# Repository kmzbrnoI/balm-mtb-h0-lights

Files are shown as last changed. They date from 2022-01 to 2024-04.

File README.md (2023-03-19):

Osvětlení vozů malý Balm H0
===========================

Tento repozitář obsahuje podklady pro výrobu dekodéru osvětlení vlečných vozů
Balm firmy MTBmodel.

Osvětlení se skládá z horní desky ([pcb](pcb), montuje se pod strop vozů) a dvou
čelních desek ([pcb-head](pcb-head)) pro koncová světla. Na horní desce je procesor
PIC12F629, do kterého se nahrává firmware ze složky [fw](fw),

## Návod k použití

Návod obsahuje popis základních parametrů osvětlení.

* [Webový návod](https://docs.google.com/document/d/e/2PACX-1vRgrOjyaV_YPN3vRX59pJFN3mEdiZDsYugB_XFN0bcXFv8iJtmIPFT6zj8s5dFSr0we1PM2x35lkkI6/pub)
* [PDF](https://drive.google.com/file/d/1UF51u17YCr2_-8sSnn3kVr8-1jqHwtga/view)

## Autoři

* Autorem DPS je [Jan Horáček](mailto:jan.horacek@kmz-brno.cz).
* Autory firmwaru jsou: Paco Canada, Michal Petrilak,
  [Jan Horáček](mailto:jan.horacek@kmz-brno.cz).

## Licence

Hardware je vydán pod licencí [Creative Commons Attribution-ShareAlike 4.0
License](https://creativecommons.org/licenses/by-sa/4.0/) jako openhardware
projekt. Kdokoliv si může stáhnout data, přispět k projektu, vyrobit si vlastní
DPS nebo dokonce vyrobené DPS využít pro komerční účely.

Firmware je převzat od [Paco](https://usuaris.tinet.cat/fmco/home_en.htm)
[Function decoder with 4 outputs v.2](https://usuaris.tinet.cat/fmco/home_en.htm).

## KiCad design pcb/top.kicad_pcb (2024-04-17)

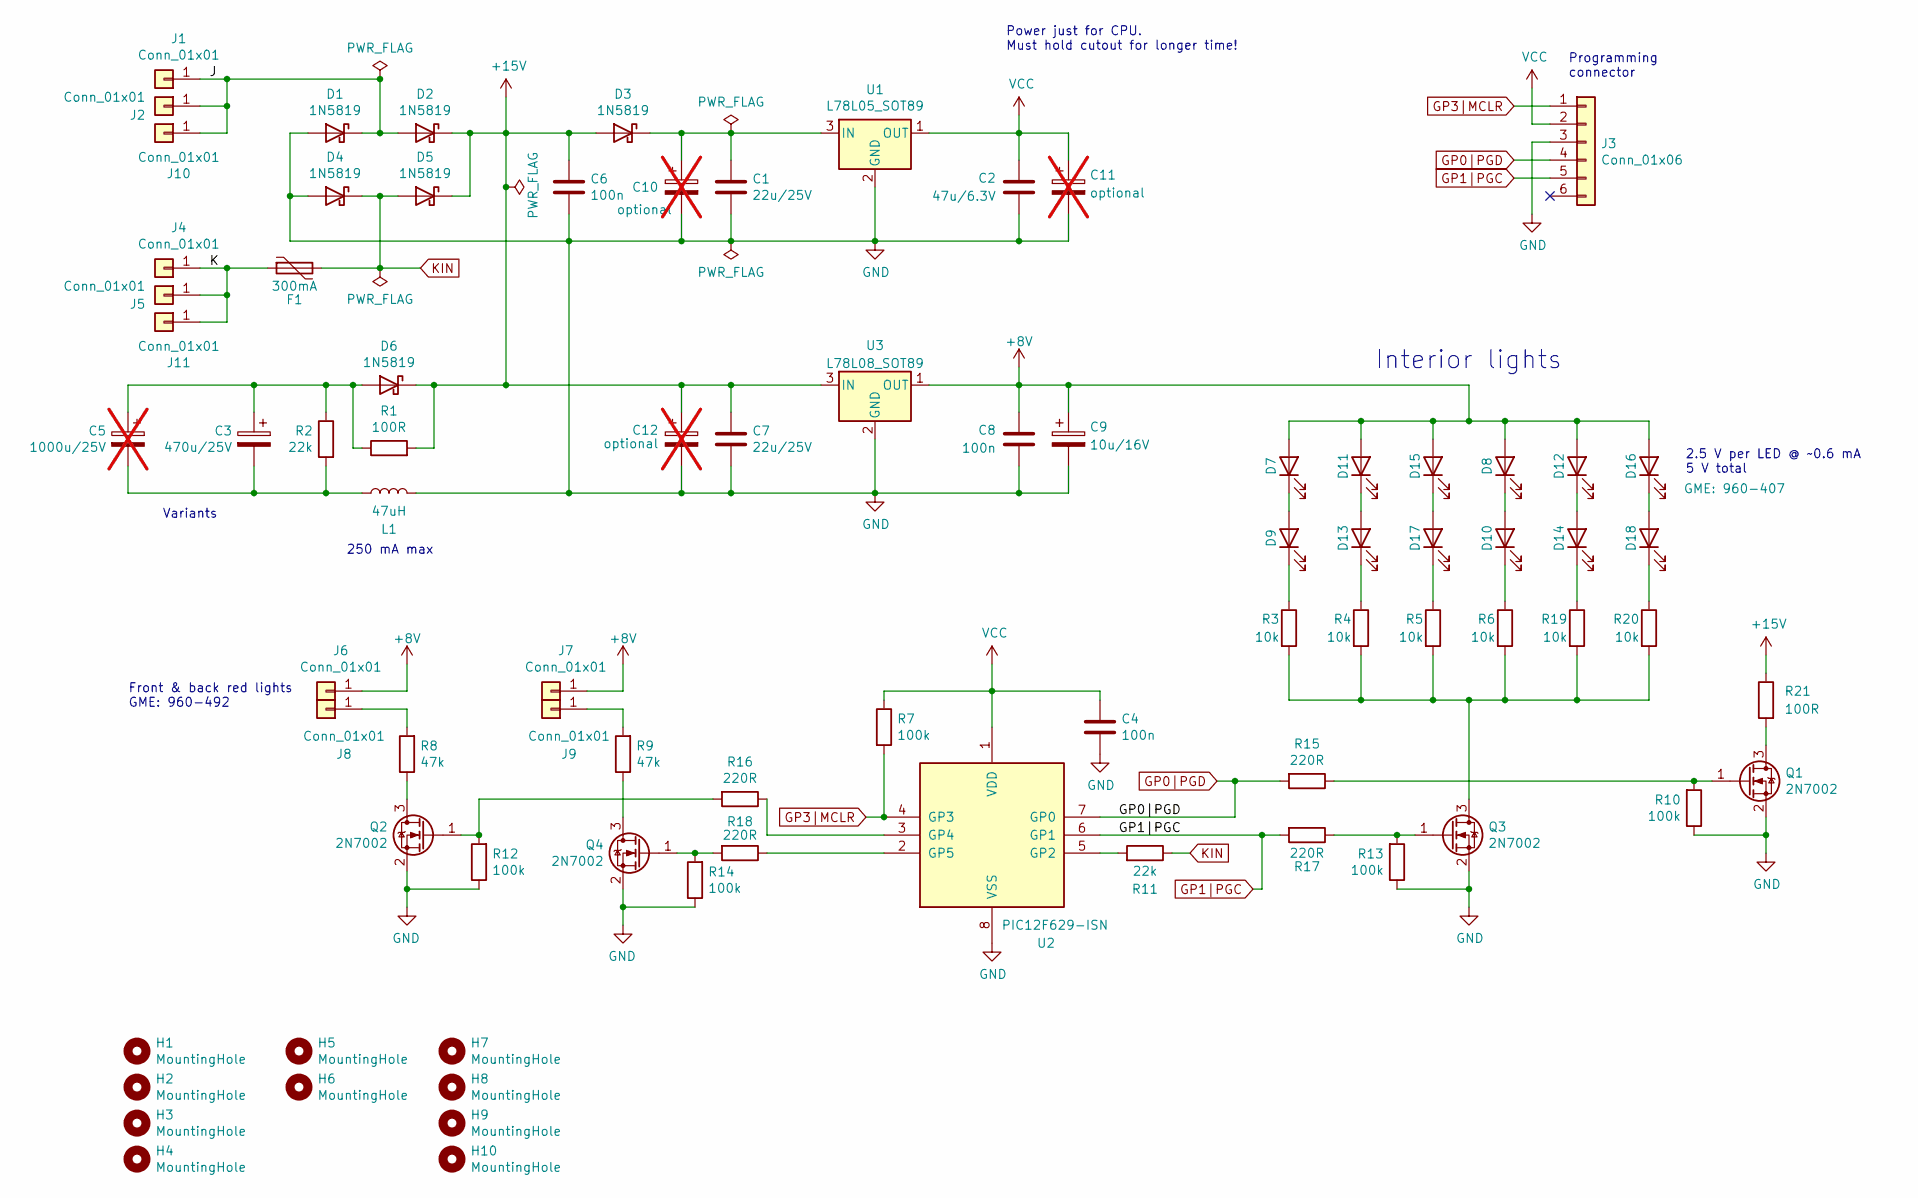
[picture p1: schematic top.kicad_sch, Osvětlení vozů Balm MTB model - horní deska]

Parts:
C1, C7: 22u/25V; C_0805_2012Metric_Pad1.18x1.45mm_HandSolder; LCSC C45783
C2: 47u/6.3V; C_0805_2012Metric_Pad1.18x1.45mm_HandSolder; LCSC C16780
C3: 470u/25V; CP_Radial_D8.0mm_P3.50mm; JLCPCB_IGNORE true
C4, C6, C8: 100n; C_0805_2012Metric_Pad1.18x1.45mm_HandSolder; LCSC C49678
C5: 1000u/25V; CP_Radial_D10.0mm_P5.00mm; JLCPCB_IGNORE true; not fitted
C9: 10u/16V; CP_EIA-3216-10_Kemet-I; LCSC C7171
C10, C11, C12: optional; CP_EIA-3216-10_Kemet-I; JLCPCB_IGNORE true; not fitted
D1, D2, D3, D4, D5, D6: 1N5819; D_SOD-123; LCSC C8598
D7, D8, D9, D10, D11, D12, D13, D14, D15, D16, D17, D18: LED; LED_PLCC_2835_Handsoldering; JLCPCB_IGNORE true
F1: 300mA; Fuse_1206_3216Metric_Pad1.42x1.75mm_HandSolder; LCSC C151132
H1, H2, H3, H4, H5, H6: MountingHole; MountingHole_2.7mm_M2.5; JLCPCB_IGNORE true
H7, H8, H9, H10: MountingHole; MountingHole_2.2mm_M2; JLCPCB_IGNORE true
J1, J2, J4, J5, J10, J11: Conn_01x01; PinHeader_1x01_P2.54mm_Vertical; JLCPCB_IGNORE true
J3: Conn_01x06; PinHeader_1x06_P2.54mm_Vertical; JLCPCB_IGNORE true
J6, J7, J8, J9: Conn_01x01; TestPoint_THTPad_D1.5mm_Drill0.7mm; JLCPCB_IGNORE true
L1: 47uH; L_Axial_L6.6mm_D2.7mm_P10.16mm_Horizontal_Vishay_IM-2; JLCPCB_IGNORE true
Q1, Q2, Q3, Q4: 2N7002; SOT-23_Handsoldering; LCSC C8545
R1, R21: 100R; R_2512_6332Metric_Pad1.40x3.35mm_HandSolder; LCSC C364154
R2, R11: 22k; R_0805_2012Metric_Pad1.20x1.40mm_HandSolder; LCSC C17560
R3, R4, R5, R6, R19, R20: 10k; R_0805_2012Metric_Pad1.20x1.40mm_HandSolder; LCSC C17414
R7, R10, R12, R13, R14: 100k; R_0805_2012Metric_Pad1.20x1.40mm_HandSolder; LCSC C149504
R8, R9: 47k; R_0805_2012Metric_Pad1.20x1.40mm_HandSolder; LCSC C17713
R15, R16, R17, R18: 220R; R_0805_2012Metric_Pad1.20x1.40mm_HandSolder; LCSC C17557
U1: L78L05_SOT89; SOT-89-3_Handsoldering; LCSC C71136
U2: PIC12F629-ISN; SOIC-8_3.9x4.9mm_P1.27mm; LCSC C8226
U3: L78L08_SOT89; SOT-89-3_Handsoldering; LCSC C122846

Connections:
+8V: C8.1, C9.1, D7.2 (A), D8.2 (A), D11.2 (A), D12.2 (A), D15.2 (A), D16.2 (A), J6.1, J7.1, U3.1 (OUT)
+15V: C6.1, C7.1, C12.1, D2.1 (K), D3.2 (A), D5.1 (K), D6.1 (K), R1.2, R21.1, U3.3 (IN)
/J: D1.1 (K), D2.2 (A), J1.1, J2.1, J10.1
/K: F1.1, J4.1, J5.1, J11.1
GND: C1.2, C2.2, C4.2, C6.2, C7.2, C8.2, C9.2, C10.2, C11.2, C12.2, D1.2 (A), D4.2 (A), J3.3, L1.1, Q1.2 (S), Q2.2 (S), Q3.2 (S), Q4.2 (S), R10.1, R12.1, R13.1, R14.1, U1.2 (GND), U2.8 (VSS), U3.2 (GND)
GP0|PGD: J3.4, R15.2, U2.7 (GP0)
GP1|PGC: J3.5, R17.2, U2.6 (GP1)
GP3|MCLR: J3.1, R7.2, U2.4 (GP3)
KIN: D4.1 (K), D5.2 (A), F1.2, R11.1
unnamed: C3.2, C5.2, L1.2, R2.2
unnamed: C1.1, C10.1, D3.1 (K), U1.3 (IN)
unnamed: C3.1, C5.1, D6.2 (A), R1.1, R2.1
unnamed: D7.1 (K), D9.2 (A)
unnamed: D9.1 (K), R3.1
unnamed: D8.1 (K), D10.2 (A)
unnamed: D10.1 (K), R6.1
unnamed: D11.1 (K), D13.2 (A)
unnamed: D12.1 (K), D14.2 (A)
unnamed: D13.1 (K), R4.1
unnamed: D14.1 (K), R19.1
unnamed: D15.1 (K), D17.2 (A)
unnamed: D16.1 (K), D18.2 (A)
unnamed: D17.1 (K), R5.1
unnamed: D18.1 (K), R20.1
unnamed: J8.1, R8.2
unnamed: J9.1, R9.2
unnamed: Q1.3 (D), R21.2
unnamed: Q1.1 (G), R10.2, R15.1
unnamed: Q2.3 (D), R8.1
unnamed: Q2.1 (G), R12.2, R16.2
unnamed: Q3.3 (D), R3.2, R4.2, R5.2, R6.2, R19.2, R20.2
unnamed: Q3.1 (G), R13.2, R17.1
unnamed: Q4.3 (D), R9.1
unnamed: Q4.1 (G), R14.2, R18.2
unnamed: R11.2, U2.5 (GP2)
unnamed: R16.1, U2.3 (GP4)
unnamed: R18.1, U2.2 (GP5)
VCC: C2.1, C4.1, C11.1, J3.2, R7.1, U1.1 (OUT), U2.1 (VDD)

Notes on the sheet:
Front & back red lights GME: 960-492
Power just for CPU. Must hold cutout for longer time!
250 mA max
Interior lights
Programming connector
Variants
2.5 V per LED @ ~0.6 mA 5 V total

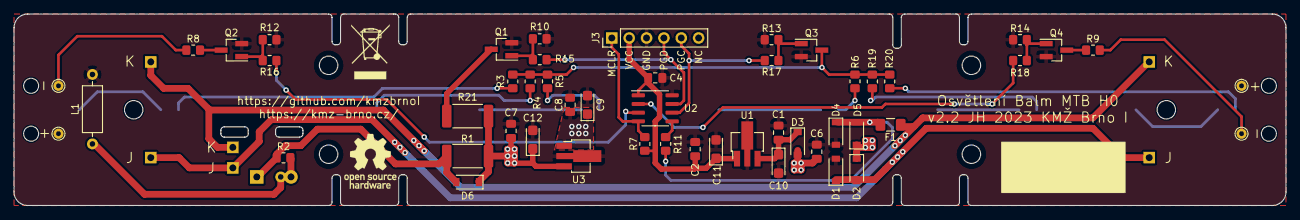
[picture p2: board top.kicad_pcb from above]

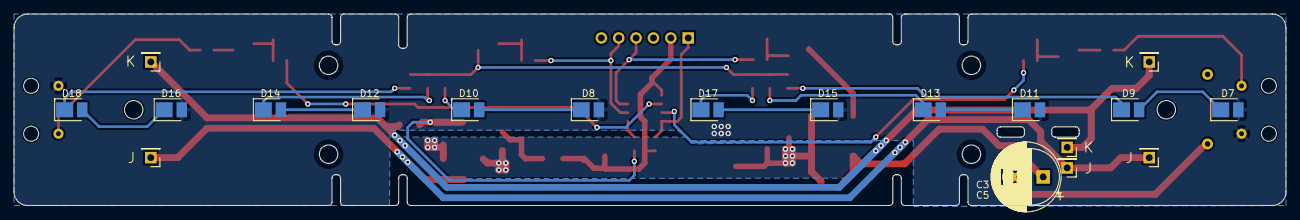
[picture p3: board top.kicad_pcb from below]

Board: 2 copper layers, 186.0 x 28.0 mm, 81 parts (20 on the bottom side), 38 nets.

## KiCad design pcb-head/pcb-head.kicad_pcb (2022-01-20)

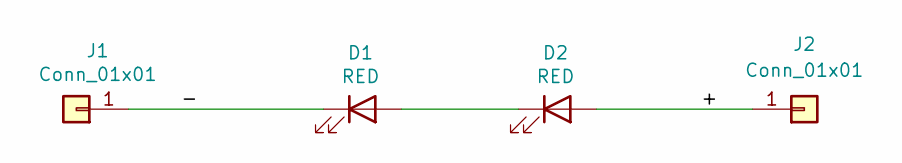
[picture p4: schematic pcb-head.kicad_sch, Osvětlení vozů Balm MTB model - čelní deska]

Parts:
D1, D2: RED; LED_0805_2012Metric_Pad1.15x1.40mm_HandSolder
J1, J2: Conn_01x01; TestPoint_THTPad_D1.5mm_Drill0.7mm

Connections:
/+: D2.2 (A), J2.1
/-: D1.1 (K), J1.1
unnamed: D1.2 (A), D2.1 (K)

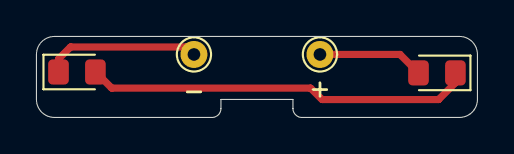
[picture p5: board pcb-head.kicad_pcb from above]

Board: 2 copper layers, 24.5 x 4.5 mm, 4 parts (0 on the bottom side), 3 nets.

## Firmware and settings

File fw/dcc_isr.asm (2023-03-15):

;;======================================================================;;
;;                      DCC FUNCTION DECODER                            ;;
;;======================================================================;;
;;                                                                      ;;
;; Program:         DCC_ISR -- DCC function decoder                     ;;
;; Code:            Paco Cañada                                         ;;
;; Platform:        Microchip PIC12F629, 4 Mhz                          ;;
;; Date:            14.07.2006                                          ;;
;; First release:   14.07.2006                                          ;;
;; LastDate:        14.07.2006                                          ;;
;;                                                                      ;;
;;======================================================================;;
;
; Minimal external components, uses internal oscilator at 4 MHz

; This program is distributed as is but WITHOUT ANY WARRANTY
; I hope you enjoy!!
;
; Revisions:
; 14.07.2006    Start of writting code
; 16.07.2006    Added fluorescent lights
; 18.07.2006    Added multiplexed mode
; 09.08.2006    Added PoM
; 30.04.2007    Added analog mode
;  1,02.2014    Removed analog, added more functions
;  8.09.2014    completed reset function
; 17.11.2014    corrected handling F13-F28 frames - no more stucks
; 29.03.2016    blink function on some outputs

; ----- Definitions

#define         __VERNUM        D'6'
#define         __VERDAY        0x10
#define         __VERMONTH      0x04
#define         __VERYEAR       0x16


        LIST       p=12F629     ; target processor

        errorlevel -305,-302

        #include P12F629.inc

        __CONFIG  _BODEN_ON & _CP_OFF & _WDT_OFF & _MCLRE_OFF & _PWRTE_ON & _INTRC_OSC_NOCLKOUT & 0x31FF

                        ; Make sure that internal osc. is calibrated
                        ; Value has to be read before reprogramming the device.
        org     0x03FF
;        retlw   0x80



; --- Macros

#define         DNOP            goto    $+1


; --- Constant values

FXTAL           equ     D'4000000'

GP_TRIS         equ     b'00000100'             ; GP2: input
GP_INI          equ     0x00                    ; all zero
OPTION_INI      equ     0x88                    ; Option register: no pull-up, falling GP2, no prescaler, wdt 1:1
WPU_INI         equ     0x33                    ; Weak pull-up enable. default, no pull-ups

INTC_INI        equ     0x88                    ; GIE, GPIE enable, PEIE disable
PIE1_INI        equ     0x00                    ; no interrupts

BLIK_DIV_P      equ     0x82                    ; blink divider preset (×3,84 ms)

E_DEF_1ex       equ     0x03                    ; short addr, long addr L, analog
E_DEF_7         equ     0x16                    ; version = 22
E_DEF_8         equ     0x0D                    ; manufacturer = DIY
E_DEF_17        equ     0xC0                    ; long addr H
E_DEF_19        equ     0x00                    ; consist
E_DEF_29        equ     0x06                    ; config (short, F1-F4)
E_DEF_33        equ     0x10                    ; F0F
E_DEF_34        equ     0x20                    ; F0R
E_DEF_3536      equ     0x02                    ; F1
E_DEF_3738      equ     0x00                    ; F2


#define         OUT1    0                       ;
#define         OUT2    1                       ;
#define         DCCIN   GPIO,2                  ; DCC input pin
#define         OUT4    4                       ;
#define         OUT5    5                       ;


; --- EEPROM Section

#define         EE_INI          0x01

E_MM            equ     0x00
E_CV1           equ     EE_INI+0x00             ; CV513 Primary Adress low
E_CV7           equ     EE_INI+0x01             ; Manufacturer Version
E_CV8           equ     EE_INI+0x02             ; Manufacturer ID
E_CV13          equ     EE_INI+0x03             ; Analog F1..F8
E_CV14          equ     EE_INI+0x04             ; Analog FL,FR (F9..F12)
E_CV17          equ     EE_INI+0x05             ; Extended Adress Low Byte
E_CV18          equ     EE_INI+0x06             ; Extended Adress High Byte
E_CV19          equ     EE_INI+0x07             ; Consist Adress
E_CV29          equ     EE_INI+0x08             ; config
E_CV33          equ     EE_INI+0x09             ; F0F -> GPIO (xx54xx10)
E_CV34          equ     EE_INI+0x0A             ; F0R -> GPIO (xx54xx10)
E_CV35          equ     EE_INI+0x0B             ; F1F -> GPIO (xx54xx10)
E_CV36          equ     EE_INI+0x0C             ; F1R -> GPIO (xx54xx10)
E_CV37          equ     EE_INI+0x0D             ; F2F -> GPIO (xx54xx10)
E_CV38          equ     EE_INI+0x0E             ; F2R -> GPIO (xx54xx10)
E_CV39          equ     EE_INI+0x0F             ; F3F -> GPIO (xx54xx10)
E_CV40          equ     EE_INI+0x10             ; F3R -> GPIO (xx54xx10)
E_CV41          equ     EE_INI+0x11             ; F4F -> GPIO (xx54xx10)
E_CV42          equ     EE_INI+0x12             ; F4R -> GPIO (xx54xx10)
E_CV43          equ     EE_INI+0x13             ; F5F -> GPIO (xx54xx10)
E_CV44          equ     EE_INI+0x14             ; F5R -> GPIO (xx54xx10)
E_CV45          equ     EE_INI+0x15             ; F6F -> GPIO (xx54xx10)
E_CV46          equ     EE_INI+0x16             ; F6R -> GPIO (xx54xx10)
E_CV47          equ     EE_INI+0x17             ; F7F -> GPIO (xx54xx10)
E_CV48          equ     EE_INI+0x18             ; F7R -> GPIO (xx54xx10)
E_CV49          equ     EE_INI+0x19             ; F8F -> GPIO (xx54xx10)
E_CV50          equ     EE_INI+0x1A             ; F8R -> GPIO (xx54xx10)
E_CV51          equ     EE_INI+0x1B             ; blik speed (× 3.84 ms)

; ----- Variables

; --- Internal RAM Section

#define         RAMINI0         0x020           ; 64 bytes

INT_W           equ     RAMINI0+0x00            ; interrupt context registers
INT_STAT        equ     RAMINI0+0x01

SHIFT0          equ     RAMINI0+0x02
DATA1           equ     RAMINI0+0x03            ; interrupt shift register
DATA2           equ     RAMINI0+0x04
DATA3           equ     RAMINI0+0x05
DATA4           equ     RAMINI0+0x06
DATA5           equ     RAMINI0+0x07
DATA6           equ     RAMINI0+0x08

PREAMBLE        equ     RAMINI0+0x09
DCCSTATE                equ     RAMINI0+0x0A
DCCBYTE         equ     RAMINI0+0x0B

F1F8SET         equ     RAMINI0+0x0C
;F1F8OLD        equ     RAMINI0+0x0D
;FSET           equ     RAMINI0+0x0E
;FCHG           equ     RAMINI0+0x0F

CV1             equ     RAMINI0+0x10            ;
CV7             equ     RAMINI0+0x11            ;
CV8             equ     RAMINI0+0x12            ;
CV13            equ     RAMINI0+0x13            ;
CV14            equ     RAMINI0+0x14            ;
CV17            equ     RAMINI0+0x15            ;
CV18            equ     RAMINI0+0x16            ;
CV19            equ     RAMINI0+0x17            ;
CV29            equ     RAMINI0+0x18            ; config
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

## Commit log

2021-12-23 Add pcb project.
2021-12-23 Add schematics.
    [top.sch]
2021-12-23 Add programming connector.
    [top.sch]
2021-12-24 Add clear footprints.
    [top.sch]
2021-12-24 Use discrete-parts rectifier.
    [top.sch]
2021-12-27 Annotate schematics.
    [top.sch]
2021-12-27 Add pcb outline.
    [top.kicad_pcb]
2021-12-27 Add LEDs package, position LEDs.
    [top.kicad_pcb, top.sch]
2021-12-29 Add MOSFET gate protection resistors.
    [top.kicad_pcb, top.sch]
2022-01-01 Add proper PCB dimensions.
    [top.kicad_pcb, top.sch]
2022-01-01 Wire part of PCB.
    [top.kicad_pcb, top.sch]
2022-01-06 Wire whole PCB.
    [top.kicad_pcb, top.sch]
2022-01-06 Tweak silkscreen etc.
    [top.kicad_pcb]
2022-01-06 Add LCSC.
    [top.sch]
2022-01-06 Apply minor fabrication corrections.
    [top.sch]
2022-01-06 Use 2512 power resistor.
    [top.kicad_pcb, top.sch]
2022-01-13 Note LED voltage.
    [top.sch]
2022-01-13 Add head pcb schematics.
    [pcb-head.kicad_pcb, pcb-head.sch]
2022-01-13 Head: add pcb dimensions & basic positions.
    [pcb-head.kicad_pcb, pcb-head.sch]
2022-01-19 Wire head pcb.
    [pcb-head.kicad_pcb]
2022-01-19 Top: switch +-.
    [pcb-head.kicad_pcb, top.kicad_pcb]
2022-01-20 Migrate to KiCad 6.
    [pcb-head.kicad_pcb, pcb-head.kicad_sch, pcb-head.sch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]
2022-01-20 Add proper mousebites position.
    [pcb-head.kicad_pcb]
2022-01-20 Remove wire stubs.
    [pcb-head.kicad_pcb]
2022-01-20 Minor enhancements to Makefile.
    [top.kicad_sch]
2022-01-20 Add OSHW logo.
    [top.kicad_pcb, top.kicad_sch]
2022-03-03 Top: add 100n capacitor on input.
    To filter DCC edges (causing transistors to open).
    [top.kicad_pcb, top.kicad_sch]
2022-03-03 Change front transistors 10k → 47k.
    [top.kicad_pcb, top.kicad_sch]
2022-03-04 Change capacitor-discharge resistor to 22k.
    [top.kicad_pcb, top.kicad_sch]
2022-03-04 Use schottky diodes on rectifier & capacitor.
    [top.kicad_pcb, top.kicad_sch]
2022-03-04 Reposition corridor LEDs to be in the middle of corridor.
    [top.kicad_pcb]
2022-03-04 Change order of LEDs to 2-2-2-2-2-2.
    [top.kicad_pcb, top.kicad_sch]
2022-03-04 Add load resistor for CV reading.
    [top.kicad_pcb, top.kicad_sch]
2022-03-04 Use 8V stabilized for LEDs.
    To keep LEDs longer running on capacitor while maintaining brightness.
    [top.kicad_pcb, top.kicad_sch]
2022-03-04 Tweak silkscreen.
    [top.kicad_pcb, top.kicad_sch]
2022-03-06 Add holes for wires.
    [top.kicad_pcb, top.kicad_sch]
2022-03-06 Add oshw & weee logos.
    [top.kicad_pcb]
2022-04-10 Sch: do not put global labels directly on corner.
    Minor schematic tweak to look better.
    [top.kicad_sch]
2022-04-16 Update fuses.
2023-03-15 Fix fuses.
2023-03-17 Change PCB color to white.
    [top.kicad_pcb]
2023-03-18 Add optinal tantalum capacitor.
    [top.kicad_pcb, top.kicad_sch]
2023-03-18 Add JLCPCB_IGNORE or LCSC number.
    [top.kicad_sch]
2023-03-18 Use SOT89 for 78L08.
    [top.kicad_pcb, top.kicad_sch]
2023-03-19 Correct JLCPCB parts orientation.
    [top.kicad_sch]
2023-03-26 Mounting holes: decrease clearance.
    Big clearance is not required, screws are small.
    [top.kicad_pcb]
2023-03-31 Enalarge interior LEDs resistors to 4k7.
    Light wa too bright.
    [top.kicad_sch]
2023-04-07 Add fuse on input.
    [top.kicad_pcb, top.kicad_sch]
2023-06-13 Use 1N5819 insteas on 1N4148.
    [top.kicad_pcb, top.kicad_sch]
2023-06-13 Add optional tantalum capacitors.
    [top.kicad_pcb, top.kicad_sch]
2023-12-19 Add thermal relief to U1 & U3.
    [top.kicad_pcb]
2023-12-23 Mark unused capacitors as DNP.
    [top.kicad_sch]
2023-12-23 Update to KiCad 7.
    [top.kicad_pcb, top.kicad_sch]
2023-12-23 Connect CPU input after fuse.
    [top.kicad_pcb, top.kicad_sch]
2023-12-23 sch: update interior LEDs current, add notes.
    [top.kicad_sch]
2023-12-23 F1: fuse -> polyfuse, 500mA -> 300mA.
    [top.kicad_sch]
2023-12-24 Add silkscreen rectangle for serial number.
    [top.kicad_pcb]
2024-04-16 Fix R20 name & value order.
    [top.kicad_sch]
2024-04-17 Use 10k resistors for interior LEDs instead of 4k7.
    Based on field testing.
    [top.kicad_pcb, top.kicad_sch]

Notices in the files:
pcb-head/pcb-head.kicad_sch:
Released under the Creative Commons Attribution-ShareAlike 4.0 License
